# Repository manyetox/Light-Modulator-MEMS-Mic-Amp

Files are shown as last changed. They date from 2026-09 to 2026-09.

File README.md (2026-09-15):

<div align="center">

# Light Modulator + MEMS Mic Amp

**A compact two-board hardware platform for experimenting with optical audio modulation and MEMS microphone response.**





**Bluetooth audio → current-modulated LED/laser → MEMS microphone → audio amplifier**

</div>

> [!WARNING]
> **Laser safety:** This project can drive visible and near-infrared laser diodes. Near-IR beams may be difficult or impossible to see. Use the lowest practical optical power, a proper beam stop/enclosure, appropriate eye protection, and never aim a beam at people or reflective surfaces.

## Overview

This project is an experimental hardware platform for studying **optical audio injection into analogue microphones**.

It consists of two PCBs:

| Transmitter | Receiver |
|---|---|
| Receives audio over Bluetooth | Supports multiple analogue microphone types |
| Mixes stereo audio to mono | Low-noise microphone preamplifier |
| Adds adjustable DC bias and modulation depth | Speaker/audio output stage |
| Drives an LED or laser with an analogue current waveform | Allows microphone-to-microphone comparison |
| Uses a closed-loop current sink | Can be monitored with an oscilloscope |

The transmitter has already been **bench-tested and is functional**. Receiver validation is ongoing.

## Prototype

The first assembled transmitter and receiver prototypes are shown below.

<p align="center">
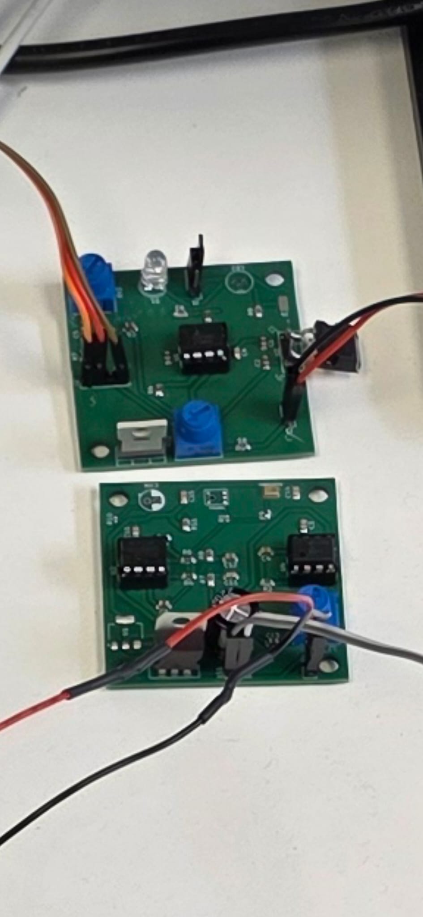
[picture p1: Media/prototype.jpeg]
Assembled transmitter and MEMS microphone receiver prototypes
  
</p>

### Prototype Demonstration

The animation below shows the assembled transmitter prototype operating and modulating the optical output from a Bluetooth audio source.

<p align="center">
  Working optical audio transmitter prototype
</p>

A longer demonstration of the prototype is also available:

▶ **[Watch the full prototype demonstration](Media/prototype-demo.mp4)**

## System Architecture

```mermaid
flowchart LR
    A[Phone / Audio Source] -->|Bluetooth| B[MH-M18]
    B --> C[Stereo-to-Mono Mix]
    C --> D[Modulation Depth]
    E[DC Bias] --> F[VSET]
    D --> F
    F --> G[CA3140 Control Loop]
    G --> H[IRLB8748 Current Sink]
    H --> I[LED / Laser]

    I -. Modulated Light .-> J[Analogue MEMS Microphone]
    J --> K[MCP6281 Preamp]
    K --> L[Volume Control]
    L --> M[LM386 Audio Amp]
    M --> N[Speaker / Oscilloscope]
```

## Transmitter

The transmitter converts Bluetooth audio into a controlled LED or laser current.
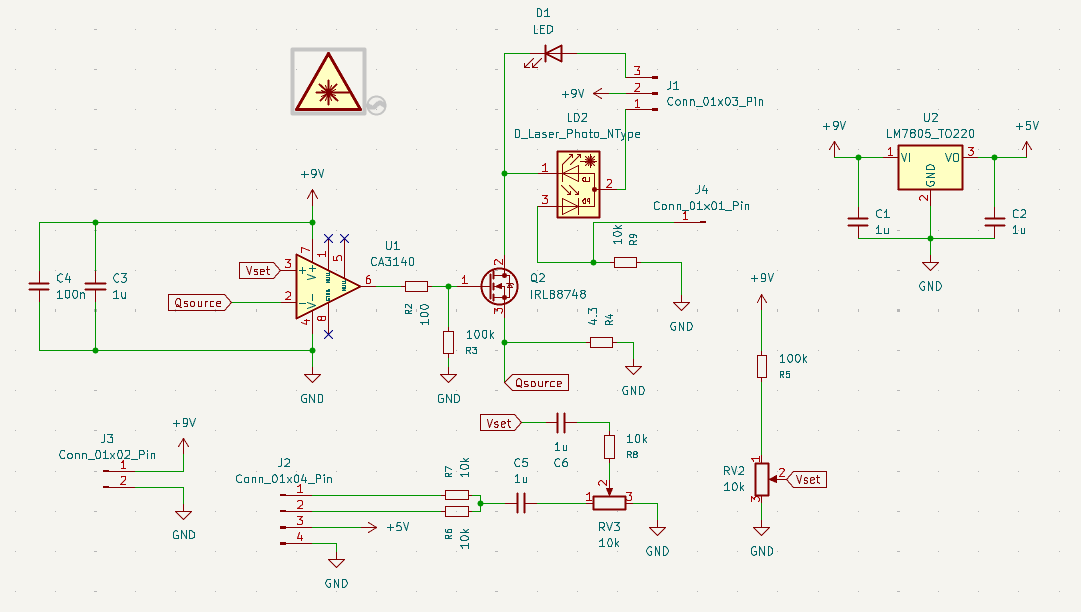
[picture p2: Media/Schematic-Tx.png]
Transmitter schematic


```text
Phone
  ↓ Bluetooth
MH-M18
  ↓
L/R audio mixed to mono
  ↓
Modulation-depth control
  ↓
DC bias + audio = VSET
  ↓
CA3140
  ↓
IRLB8748 current sink
  ↓
LED / laser diode
```

The CA3140 compares the requested control voltage (`VSET`) with the voltage across the current-sense resistor and drives the IRLB8748 until they match.

The approximate optical-source current is:

$$
I_{LED} \approx \frac{V_{SET}}{R_{SENSE}}
$$

This causes the LED or laser brightness to follow the audio waveform while maintaining an adjustable DC operating point.

### Main Transmitter Components

| Component | Function |
|---|---|
| **MH-M18** | Bluetooth audio receiver |
| **CA3140** | Current-control error amplifier |
| **IRLB8748** | Power MOSFET / controlled current sink |
| **LM7805** | 5 V supply for Bluetooth module |
| **RV2** | DC bias / optical operating point |
| **RV3** | Audio modulation depth |
| **R<sub>SENSE</sub>** | Sets the current range |

<details>
<summary><strong>Current-limit examples</strong></summary>

With the present bias network, the maximum DC `VSET` is approximately **0.82 V**.

| R<sub>SENSE</sub> | Approx. maximum DC current |
|---:|---:|
| 120 Ω | 6.8 mA |
| 22 Ω | 37 mA |
| 16.2 Ω | 51 mA |
| 4.3 Ω | 190 mA |

The resistor must be selected for the specific LED or laser being tested.

Audio modulation can create instantaneous current peaks above the DC operating point.

</details>

## Receiver

The receiver is designed to make the microphone response easy to hear and measure.

```text
Analogue microphone
  ↓
AC coupling
  ↓
MCP6281 preamplifier
  ↓
Volume control
  ↓
LM386 audio amplifier
  ↓
8 Ω speaker / oscilloscope
```

### Microphone Options

The receiver platform is intended for comparison between different analogue microphone technologies, including:

- **Infineon IM68A130** analogue MEMS microphone
- **TDK InvenSense ICS-40300** analogue MEMS microphone
- **ADMP401 breakout module** as a reference microphone
- Conventional electret microphone for control measurements

The onboard MCP6281 stage provides approximately **×48 voltage gain** for low-level microphone signals.

The LM386 provides the final power amplification for an 8 Ω speaker.

> [!NOTE]
> The ADMP401 breakout includes its own amplification, so it should be evaluated separately before feeding it through the full onboard microphone gain stage.

## Quick Start

1. **Choose the optical source.** Start with an LED before moving to a laser diode.
2. **Set the current range.** Select `R_SENSE` for the required current before connecting the optical device.
3. **Power the transmitter.** Verify the supply rails before fitting the LED or laser.
4. **Connect Bluetooth audio.** Pair a phone with the MH-M18 and play a low-volume test signal.
5. **Set the DC bias.** Increase the optical operating point gradually.
6. **Add modulation.** Increase the modulation-depth control while observing the output on an oscilloscope if available.
7. **Test the receiver.** Aim the modulated light at the microphone and monitor the recovered signal through the speaker or oscilloscope.

## Project Goals

This project is intended as a practical experimental platform for:

- reproducing and exploring optical-to-electrical coupling in analogue MEMS microphones;
- comparing microphone responses across different devices and optical wavelengths;
- testing different modulation depths, bias currents and optical sources;
- providing an inexpensive alternative to laboratory-only modulation hardware;
- making the phenomenon easy to demonstrate and measure on the bench.

## Project Status

| Subsystem | Status |
|---|---|
| Bluetooth audio input | ✅ Bench tested |
| Audio mixing / modulation | ✅ Bench tested |
| CA3140 + IRLB8748 current control | ✅ Bench tested |
| LED modulation | ✅ Bench tested |
| Laser-diode operation | 🧪 Device-dependent testing |
| MEMS receiver PCB | 🧪 Prototype / validation |
| Multi-microphone comparison | 🔬 Planned testing |

## Background

This project is inspired by the research presented in:

**T. Sugawara, B. Cyr, S. Rampazzi, D. Genkin and K. Fu,  
“Light Commands: Laser-Based Audio Injection Attacks on Voice-Controllable Systems,”  
29th USENIX Security Symposium, 2020.**

- [USENIX paper and presentation](https://www.usenix.org/conference/usenixsecurity20/presentation/sugawara)
- [Light Commands project website](https://lightcommands.com/)

The original research demonstrated that amplitude-modulated light can induce electrical signals in MEMS microphones.

This repository is an **independent experimental hardware implementation** intended for controlled research and educational testing.

## Safety and Responsible Use

This repository is intended for **laboratory, educational and defensive research**.

Do not direct lasers at people, vehicles, cameras, public devices or equipment you do not own or have explicit permission to test.

Use appropriate laser controls for the wavelength and optical power being used.

Infrared laser sources deserve particular care because the beam may not be visible.

## Contributing

Suggestions, measurements, microphone comparisons and hardware improvements are welcome.

For substantial changes, please open an issue first so the proposed change can be discussed before a pull request is prepared.

Useful contributions include:

- measurements from additional analogue MEMS microphones;
- optical wavelength comparisons;
- PCB and layout improvements;
- current-control stability measurements;
- oscilloscope captures and frequency-response data;
- documentation corrections.

## License

Copyright © 2026 Taylan Arslan.

This project is available for **research, educational, academic, personal, and other non-commercial use** under the terms of the [`LICENSE.md`](LICENSE.md) file.

**Commercial use is not permitted under the public license.**

Commercial manufacture, integration into a commercial product or service, internal commercial R&D, resale, or other commercial exploitation requires a **separate commercial license from the author**.

Commercial licenses may be provided for a fee. For commercial licensing enquiries, please contact **Taylan Arslan**.

The project is provided **as-is, without warranty**. Users are responsible for verifying the design, selecting appropriate components, complying with applicable regulations, and following electrical and laser-safety requirements.

See [`LICENSE.md`](LICENSE.md) for the complete terms.
## Author

**Taylan Arslan**

GitHub: [@manyetox](https://github.com/manyetox)

---

<div align="center">

### Light in. Audio out.

If this project helps your research, consider starring the repository.

</div>

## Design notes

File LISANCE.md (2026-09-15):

TAYLAN ARSLAN RESEARCH AND NON-COMMERCIAL HARDWARE LICENSE
Version 1.0

Copyright (c) 2026 Taylan Arslan
All rights reserved except as expressly granted below.

1. DEFINITIONS

"Project" means all materials made available in this repository, including
but not limited to:

- electronic schematics;
- PCB layouts;
- KiCad source files;
- Gerber and manufacturing files;
- bills of materials;
- mechanical designs;
- source code and firmware;
- documentation;
- diagrams;
- photographs;
- test data; and
- derivative or modified versions of any of the above.

"Licensor" means Taylan Arslan.

"You" means any individual or organisation exercising rights under this
license.

"Non-Commercial Use" means use primarily intended for research, education,
personal experimentation, academic work, teaching, hobby use, or other
purposes that are not intended to generate commercial advantage or monetary
compensation.

"Commercial Use" means use of the Project, directly or indirectly, in
connection with commercial activity or commercial advantage, including but
not limited to:

- selling products incorporating or derived from the Project;
- manufacturing products for sale;
- providing paid services using the Project;
- incorporating the Project into a commercial product or service;
- licensing, sublicensing, or selling the Project or a derivative work;
- using the Project as part of commercial product development;
- using the Project internally for the development, testing, manufacture,
  or improvement of a commercial product or service; or
- any other use primarily intended to obtain commercial advantage or
  monetary compensation.

2. NON-COMMERCIAL LICENSE GRANT

Subject to the terms of this license, the Licensor grants You a worldwide,
royalty-free, non-exclusive, non-transferable license to use, reproduce,
study, test, manufacture, modify, and create derivative works from the
Project solely for Non-Commercial Use.

You may manufacture prototypes based on the Project for research,
educational, academic, experimental, or personal purposes.

3. RESEARCH AND EDUCATIONAL USE

Universities, schools, students, academic researchers, non-profit research
organisations, and individuals may use and modify the Project for
Non-Commercial Use.

Publication of research results obtained using the Project is permitted.

Where reasonably practical, publications, presentations, derivative
repositories, and public demonstrations using the Project should identify:

    Original design: Taylan Arslan

and provide a link to the original repository.

4. REDISTRIBUTION AND MODIFICATIONS

You may redistribute the Project or modified versions of the Project for
Non-Commercial Use provided that:

a. this license and all copyright notices are retained;

b. the original author is identified as Taylan Arslan;

c. modified versions are clearly identified as modified and must not be
   represented as original designs of the Licensor; and

d. the redistribution does not impose terms that permit Commercial Use
   without a separate commercial license from the Licensor.

Redistribution under this section does not grant any right to sell,
commercially manufacture, commercially license, or commercially exploit
the Project.

5. COMMERCIAL USE

No Commercial Use is granted under this license.

Any person or organisation wishing to use the Project for a Commercial Use
must obtain a separate written commercial license from the Licensor.

Commercial licenses may be offered for a fee and may include terms such as:

- one-time license fees;
- annual license fees;
- per-product or per-unit royalties;
- manufacturing rights;
- modification rights;
- sublicensing rights; or
- other terms separately agreed in writing.

The Licensor is under no obligation to offer a commercial license or to
offer the same commercial terms to different parties.

Commercial licensing enquiries should be directed to Taylan Arslan through
the contact information provided in the repository.

6. RESERVATION OF RIGHTS

All rights not expressly granted by this license are reserved by the
Licensor.

Publication of the Project's source files does not place the Project in the
public domain and does not constitute permission for unrestricted use.

No rights are granted to trademarks, trade names, branding, or logos of
the Licensor.

No patent rights are granted except where a separate written agreement
expressly provides otherwise.

7. NO WARRANTY

THE PROJECT IS PROVIDED "AS IS" AND "AS AVAILABLE", WITHOUT WARRANTY OF ANY
KIND, EXPRESS OR IMPLIED.

TO THE MAXIMUM EXTENT PERMITTED BY APPLICABLE LAW, THE LICENSOR DISCLAIMS
ALL WARRANTIES, INCLUDING BUT NOT LIMITED TO WARRANTIES OF:

- MERCHANTABILITY;
- FITNESS FOR A PARTICULAR PURPOSE;
- NON-INFRINGEMENT;
- ACCURACY;
- RELIABILITY;
- SAFETY;
- PERFORMANCE;
- FITNESS FOR MANUFACTURE; AND
- FITNESS FOR USE WITH ANY PARTICULAR ELECTRICAL, OPTICAL, MECHANICAL, OR
  SOFTWARE SYSTEM.

THE LICENSOR DOES NOT WARRANT THAT THE PROJECT IS ERROR-FREE, SAFE,
COMPLETE, SUITABLE FOR PRODUCTION, OR COMPLIANT WITH ANY PARTICULAR
REGULATORY STANDARD.

8. ASSUMPTION OF RISK

The Project is experimental hardware intended primarily for research,
education, and controlled laboratory testing.

Electronic circuits, laser diodes, optical sources, batteries, power
supplies, and related equipment may cause injury, eye damage, electrical
damage, fire, equipment damage, or other hazards if designed, assembled,
modified, or operated incorrectly.

You are solely responsible for:

- evaluating the suitability of the Project for your intended use;
- verifying all component ratings and electrical limits;
- following applicable electrical and laser safety procedures;
- providing appropriate protective equipment;
- complying with applicable laws, regulations, and safety standards; and
- safely manufacturing, assembling, testing, modifying, and operating any
  hardware derived from the Project.

By using the Project, You acknowledge and accept these risks.

9. LASER AND OPTICAL SAFETY

The Project may be capable of controlling laser diodes or other optical
emitters.

The presence of a design, component, current setting, wavelength,
recommendation, example, or test result in this repository does not mean
that the resulting optical system is eye-safe or suitable for unrestricted
use.

You are responsible for determining the laser classification of the
complete assembled system and for implementing appropriate engineering
controls, enclosures, beam stops, protective eyewear, warnings, operating
procedures, and access controls.

The Project must not be used to intentionally expose people or animals to
hazardous optical radiation or to interfere with vehicles, aircraft,
public infrastructure, or equipment without authorisation.

10. LIMITATION OF LIABILITY

TO THE MAXIMUM EXTENT PERMITTED BY APPLICABLE LAW, IN NO EVENT SHALL THE
LICENSOR BE LIABLE FOR ANY CLAIM, LOSS, COST, DAMAGE, OR OTHER LIABILITY
ARISING FROM OR RELATED TO THE PROJECT OR ITS USE, INCLUDING WITHOUT
LIMITATION:

- DIRECT DAMAGES;
- INDIRECT DAMAGES;
- INCIDENTAL DAMAGES;
- SPECIAL DAMAGES;
- CONSEQUENTIAL DAMAGES;
- LOSS OF PROFITS;
- LOSS OF REVENUE;
- LOSS OF DATA;
- BUSINESS INTERRUPTION;
- PROPERTY DAMAGE;
- EQUIPMENT DAMAGE;
- PERSONAL INJURY; OR
- DAMAGE ARISING FROM THE MANUFACTURE, ASSEMBLY, MODIFICATION, TESTING,
  DISTRIBUTION, OR OPERATION OF HARDWARE BASED ON THE PROJECT,

WHETHER ARISING IN CONTRACT, TORT, NEGLIGENCE, STRICT LIABILITY, OR ANY
OTHER LEGAL THEORY, EVEN IF THE LICENSOR HAS BEEN ADVISED OF THE
POSSIBILITY OF SUCH DAMAGE.

Nothing in this license excludes or limits liability to the extent that
such liability cannot lawfully be excluded or limited.

11. RESPONSIBILITY FOR MODIFICATIONS

The Licensor is not responsible for modifications, derivative works,
manufacturing errors, component substitutions, assembly errors, incorrect
settings, or other changes made by You or any third party.

Any modified or manufactured implementation must be independently
validated before use.

12. NO SAFETY-CRITICAL RELIANCE

Unless separately authorised in writing by the Licensor, the Project is
not designed, certified, or intended for use in:

- medical equipment;
- life-support systems;
- aviation or aerospace safety systems;
- automotive safety systems;
- emergency systems;
- weapons;
- nuclear systems; or
- other applications where failure could reasonably result in death,
  serious injury, or significant property or environmental damage.

13. NO ENDORSEMENT

Use of the Project does not give You permission to state or imply that the
Licensor endorses, approves, certifies, sponsors, or is affiliated with
your product, research, organisation, or derivative work.

14. TERMINATION

Your rights under this license terminate automatically if You materially
violate its terms.

If the violation is capable of correction, the Licensor may, at the
Licensor's discretion, restore the license after the violation has been
fully corrected.

Termination of this non-commercial license does not affect any separate
commercial license previously entered into in writing.

15. SEPARATE COMMERCIAL AGREEMENTS

The Licensor may offer separate licenses granting rights that are not
provided under this license.

A separate commercial agreement may override specific provisions of this
license only where that agreement expressly states so.

Nothing in this license prevents the Licensor from licensing the same
Project to other parties under different terms.

16. THIRD-PARTY MATERIAL

This license applies only to portions of the Project for which the Licensor
owns or controls the relevant rights.

Third-party components, libraries, software, trademarks, reference designs,
research papers, or other materials remain subject to their respective
licenses and terms.

You are responsible for complying with those third-party terms.

17. SEVERABILITY

If any provision of this license is held to be invalid or unenforceable,
that provision shall be limited or removed only to the minimum extent
necessary, and the remaining provisions shall continue in effect.

18. ACCEPTANCE

By exercising any rights granted under this license, You acknowledge that
You have read, understood, and agreed to these terms.

If You do not agree to these terms, You receive no rights under this
license.

Copyright (c) 2026 Taylan Arslan.
All rights reserved except as expressly granted above.

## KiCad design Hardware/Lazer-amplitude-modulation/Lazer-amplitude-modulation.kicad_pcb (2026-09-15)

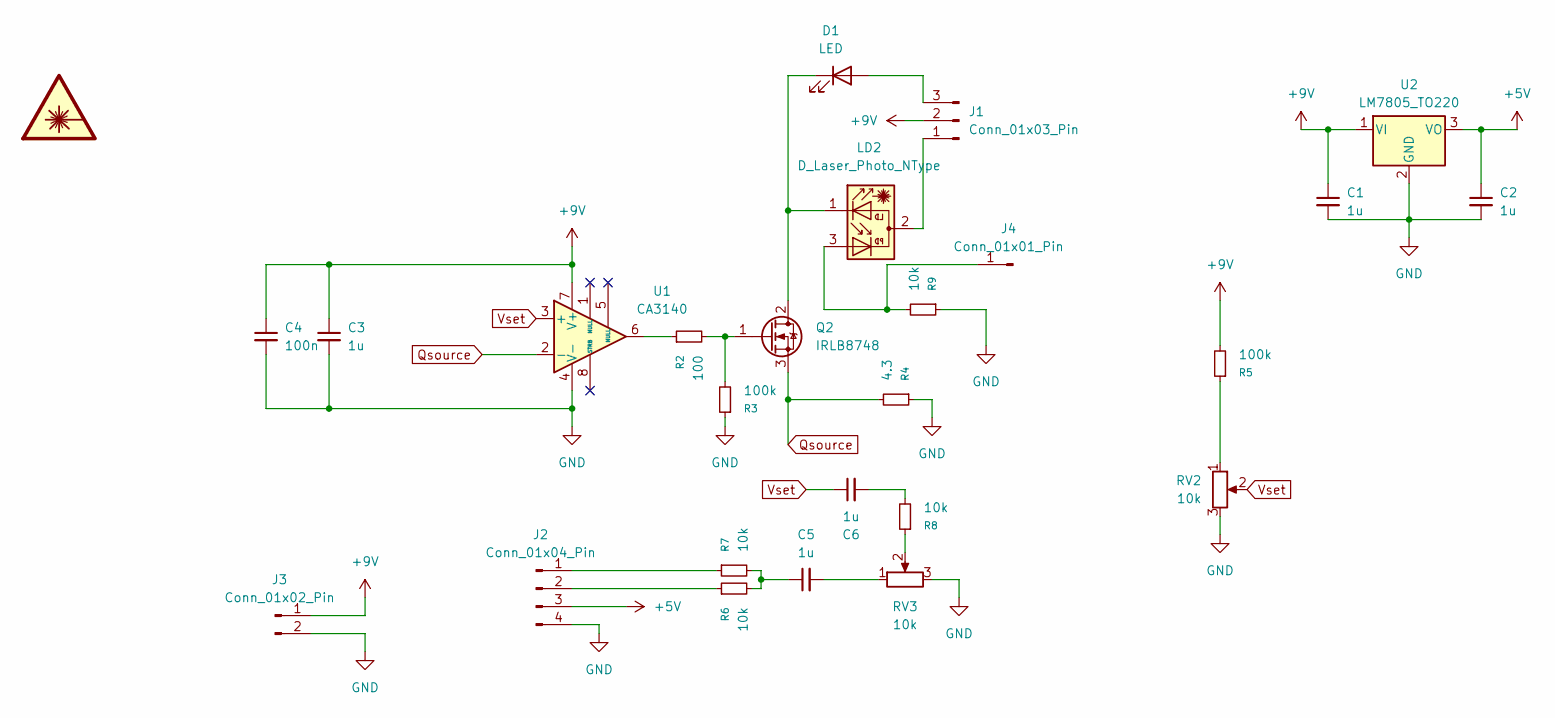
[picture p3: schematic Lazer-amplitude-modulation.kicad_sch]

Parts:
C1, C2, C3, C5, C6: 1u; C_0805_2012Metric_Pad1.18x1.45mm_HandSolder
C4: 100n; C_0805_2012Metric_Pad1.18x1.45mm_HandSolder
D1: LED; LED_D5.0mm
J1: Conn_01x03_Pin; PinHeader_1x03_P2.54mm_Vertical
J2: Conn_01x04_Pin; PinHeader_1x04_P2.54mm_Vertical
J3: Conn_01x02_Pin; PinHeader_1x02_P2.54mm_Vertical
J4: Conn_01x01_Pin; SolderWirePad_1x01_SMD_2x4mm
LD2: D_Laser_Photo_NType; LaserDiode_TO56-3
Q2: IRLB8748; TO-220-3_Vertical
R2: 100; R_0805_2012Metric_Pad1.20x1.40mm_HandSolder
R3, R5: 100k; R_0805_2012Metric_Pad1.20x1.40mm_HandSolder
R4: 4.3; R_0805_2012Metric_Pad1.20x1.40mm_HandSolder
R6, R7, R8, R9: 10k; R_0805_2012Metric_Pad1.20x1.40mm_HandSolder
RV2, RV3: 10k; Potentiometer_Bourns_3386F_Vertical
U1: CA3140; DIP-8_W7.62mm
U2: LM7805_TO220; TO-220-3_Vertical

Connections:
+5V: C2.1, J2.3, U2.3 (VO)
+9V: C1.1, C3.1, C4.1, J1.2, J3.1, R5.2, U1.7 (V+), U2.1 (VI)
GND: C1.2, C2.2, C3.2, C4.2, J2.4, J3.2, R3.1, R4.1, R9.1, RV2.3, RV3.3, U1.4 (V-), U2.2 (GND)
unnamed: C5.1, R6.2, R7.2
unnamed: C5.2, RV3.1
unnamed: C6.2, R8.2
unnamed: D1.2 (A), J1.3
unnamed: D1.1 (K), LD2.1, Q2.2 (D)
unnamed: J1.1, LD2.2
unnamed: J2.1, R7.1
unnamed: J2.2, R6.1
unnamed: J4.1 (Pin_1_1), LD2.3, R9.2
unnamed: Q2.1 (G), R2.2, R3.2
unnamed: R2.1, U1.6
unnamed: R5.1, RV2.1
unnamed: R8.1, RV3.2
Qsource: Q2.3 (S), R4.2, U1.2 (-)
Vset: C6.1, RV2.2, U1.3 (+)

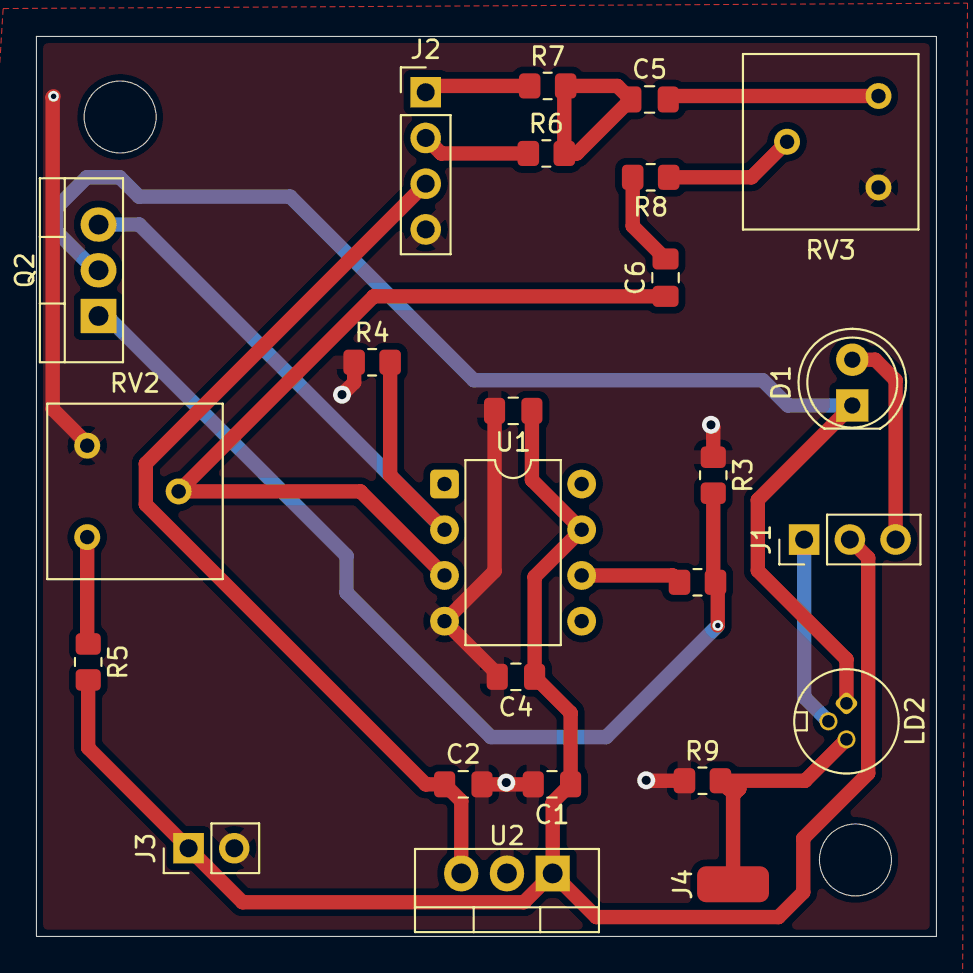
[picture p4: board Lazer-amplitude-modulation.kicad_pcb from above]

Board: 2 copper layers, 50.0 x 50.0 mm, 25 parts (0 on the bottom side), 18 nets.

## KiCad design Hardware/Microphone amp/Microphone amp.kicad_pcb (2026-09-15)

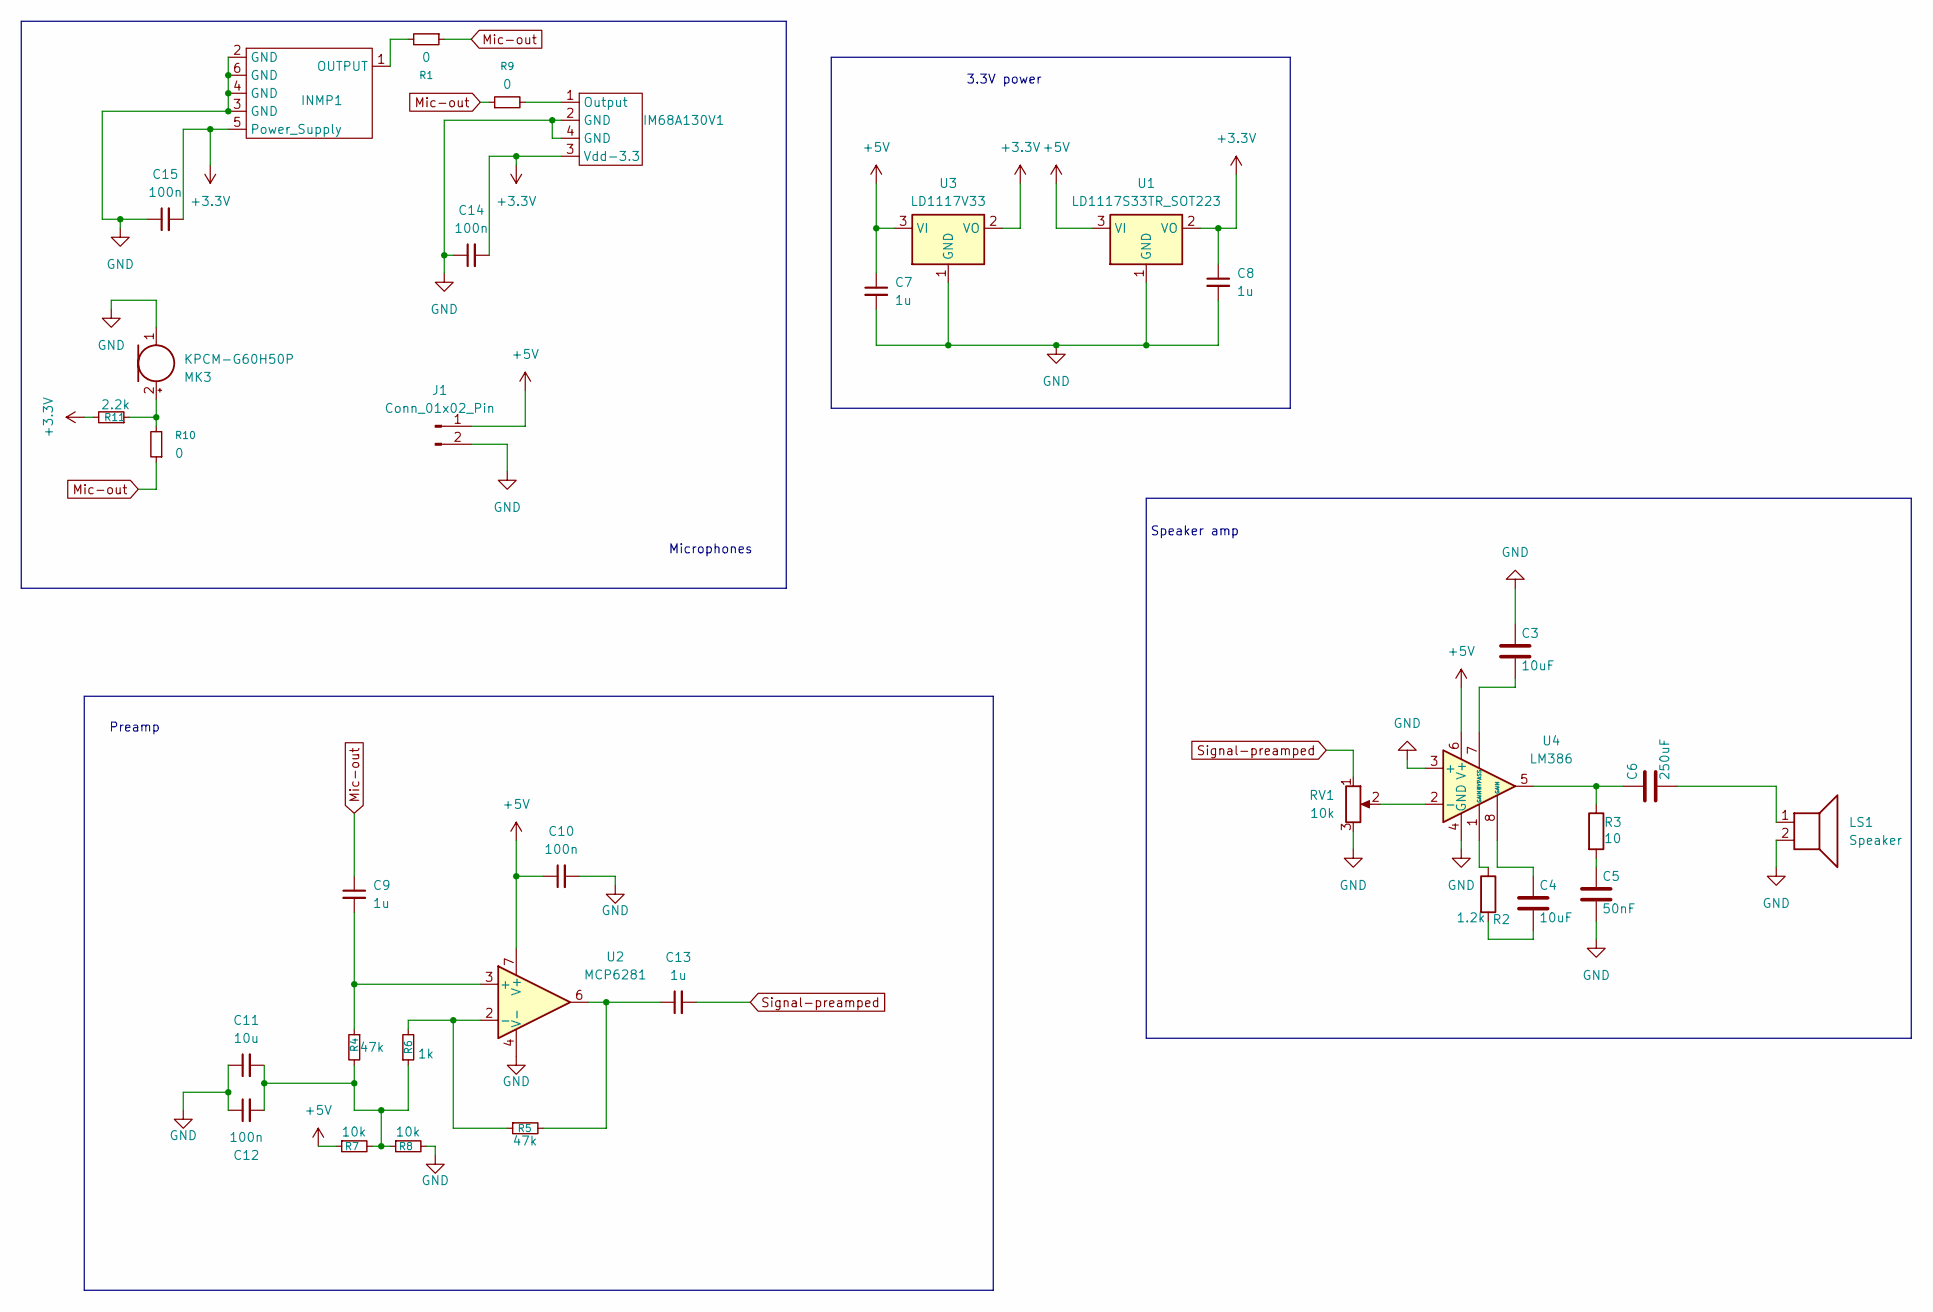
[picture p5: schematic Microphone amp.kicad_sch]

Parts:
C3, C4: 10uF; C_0805_2012Metric_Pad1.18x1.45mm_HandSolder
C5: 50nF; C_0805_2012Metric_Pad1.18x1.45mm_HandSolder
C6: 250uF; C_Radial_D6.3mm_H7.0mm_P2.50mm
C7, C8, C9, C13: 1u; C_0805_2012Metric_Pad1.18x1.45mm_HandSolder
C10, C12, C14, C15: 100n; C_0805_2012Metric_Pad1.18x1.45mm_HandSolder
C11: 10u; C_0805_2012Metric_Pad1.18x1.45mm_HandSolder
IM68A130V1: IM68A130V01
INMP1: INMP411
J1: Conn_01x02_Pin; PinHeader_1x02_P2.54mm_Vertical
LS1: Speaker; PinHeader_1x02_P2.54mm_Vertical
MK3: KPCM-G60H50P; CP_Radial_D5.0mm_P2.00mm
R1, R9, R10: 0; R_0402_1005Metric
R2: 1.2k; R_0805_2012Metric_Pad1.20x1.40mm_HandSolder
R3: 10; R_0805_2012Metric_Pad1.20x1.40mm_HandSolder
R4, R5: 47k; R_0805_2012Metric_Pad1.20x1.40mm_HandSolder
R6: 1k; R_0805_2012Metric_Pad1.20x1.40mm_HandSolder
R7, R8: 10k; R_0805_2012Metric_Pad1.20x1.40mm_HandSolder
R11: 2.2k; R_0805_2012Metric_Pad1.20x1.40mm_HandSolder
RV1: 10k; Potentiometer_Bourns_3386F_Vertical
U1: LD1117S33TR_SOT223; SOT-223-3_TabPin2
U2: MCP6281; DIP-8_W7.62mm
U3: LD1117V33; TO-220-3_Vertical
U4: LM386; DIP-8_W7.62mm_LongPads

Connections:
+3.3V: C8.1, C14.2, C15.2, IM68A130V1.3 (Vdd-3.3), INMP1.5 (Power_Supply), R11.2, U1.2 (VO), U3.2 (VO)
+5V: C7.1, C10.1, J1.1, R7.1, U1.3 (VI), U2.7 (V+), U3.3 (VI), U4.6 (V+)
GND: C3.1, C5.2, C7.2, C8.2, C10.2, C11.1, C12.1, C14.1, C15.1, IM68A130V1.2 (GND), IM68A130V1.4 (GND), INMP1.2 (GND), INMP1.3 (GND), INMP1.4 (GND), INMP1.6 (GND), J1.2, LS1.2, MK3.1 (-), R8.2, RV1.3, U1.1 (GND), U2.4 (V-), U3.1 (GND), U4.3 (+), U4.4 (GND)
Mic-out: C9.1, R1.1, R9.1, R10.1
unnamed: C4.1, U4.8 (GAIN)
unnamed: C4.2, R2.2
unnamed: C5.1, R3.2
unnamed: C6.1, R3.1, U4.5
unnamed: C6.2, LS1.1
unnamed: C11.2, C12.2, R4.2, R6.1, R7.2, R8.1
unnamed: C13.1, R5.2, U2.6
unnamed: IM68A130V1.1 (Output), R9.2
unnamed: INMP1.1 (OUTPUT), R1.2
unnamed: MK3.2 (+), R10.2, R11.1
unnamed: R2.1, U4.1 (GAIN)
unnamed: C9.2, R4.1, U2.3 (+)
unnamed: R5.1, R6.2, U2.2 (-)
unnamed: RV1.2, U4.2 (-)
unnamed: C3.2, U4.7 (BYPASS)
Signal-preamped: C13.2, RV1.1

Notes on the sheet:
Preamp
Microphones
Speaker amp
3.3V power

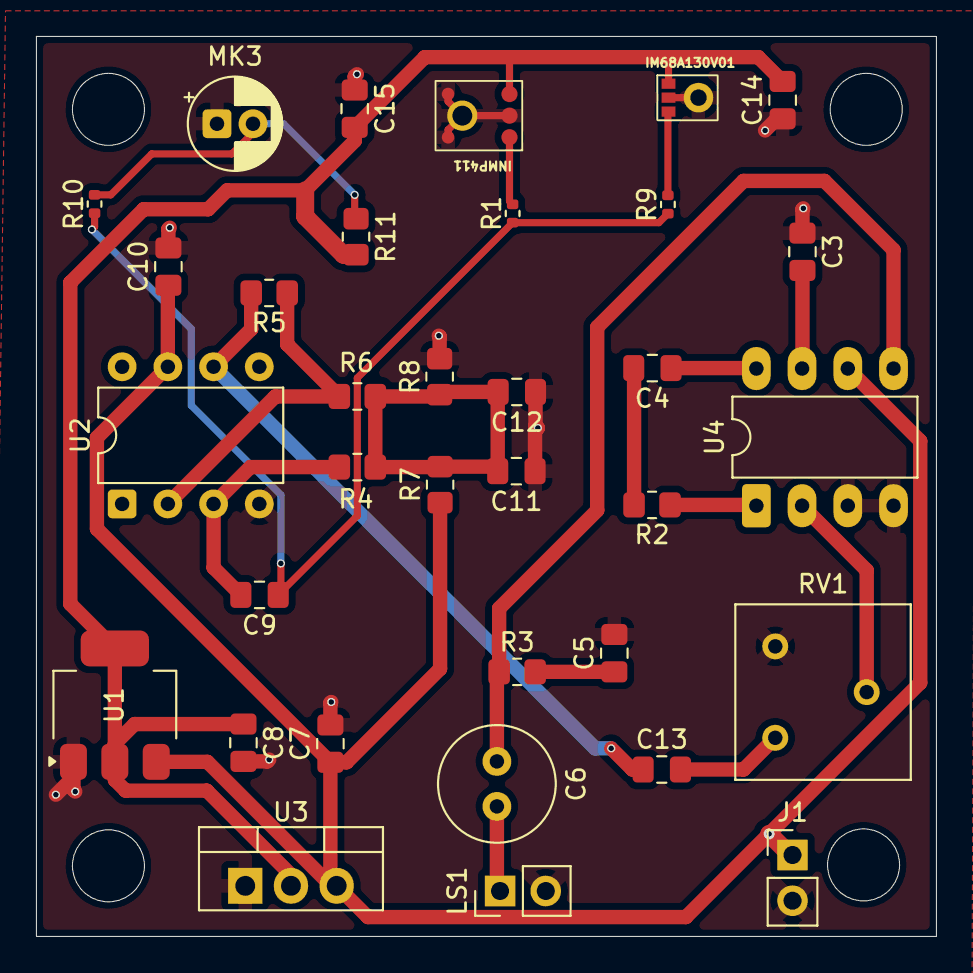
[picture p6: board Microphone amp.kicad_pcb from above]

Board: 2 copper layers, 50.0 x 50.0 mm, 34 parts (0 on the bottom side), 20 nets.

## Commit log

2026-09-15 hardware
    hardware added
    [Lazer-amplitude-modulation-B_Cu.gbr, Lazer-amplitude-modulation-B_Mask.gbr, Lazer-amplitude-modulation-B_Paste.gbr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]
2026-09-15 Media
    photo and video of the prototype are added
2026-09-15 added schematictx
